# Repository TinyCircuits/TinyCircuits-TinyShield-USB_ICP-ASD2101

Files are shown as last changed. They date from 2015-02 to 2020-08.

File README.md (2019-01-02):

# TinyCircuits TinyShield USB & ICP Board
# ASD2101 Rev6

The design files are located under design-files/ for the TinyCircuits ASD2101 Rev 6 PCB.  This is a TinyShield board (Square Version, 20mm x 20mm) that has a FTDI USB converter.

Format is in Cadsoft Eagle format - Eagle version 6.2 was used for the original design.

For more infomation on this, check out the product page at TinyCircuits.com:  https://tinycircuits.com/collections/communication/products/usb-tinyshield

# License:

Design by TinyCircuits.
All design files are released under the Creative Commons Attribution Share-Alike 3.0 License, see the following link for details: http://creativecommons.org/licenses/by-sa/3.0

All text above must be included in any redistribution or derived design

This project uses designs and concepts developed as part of the Arduino project and the LilyPad project.  The TinyCircuits design files themselves (schematics, PCB and libraries) are not directly derived from these works' design files and have been created new, however the concepts and basic architecture behind the TinyDuino and TinyLily products are derived and we thank the hard work of the organizations below for their contributions to open-source hardware:
  
Original Arduino Uno Design by Team Arduino

LilyPad Arduino Design by Leah Buechley and Sparkfun Electronics

Please support the open-source hardware community

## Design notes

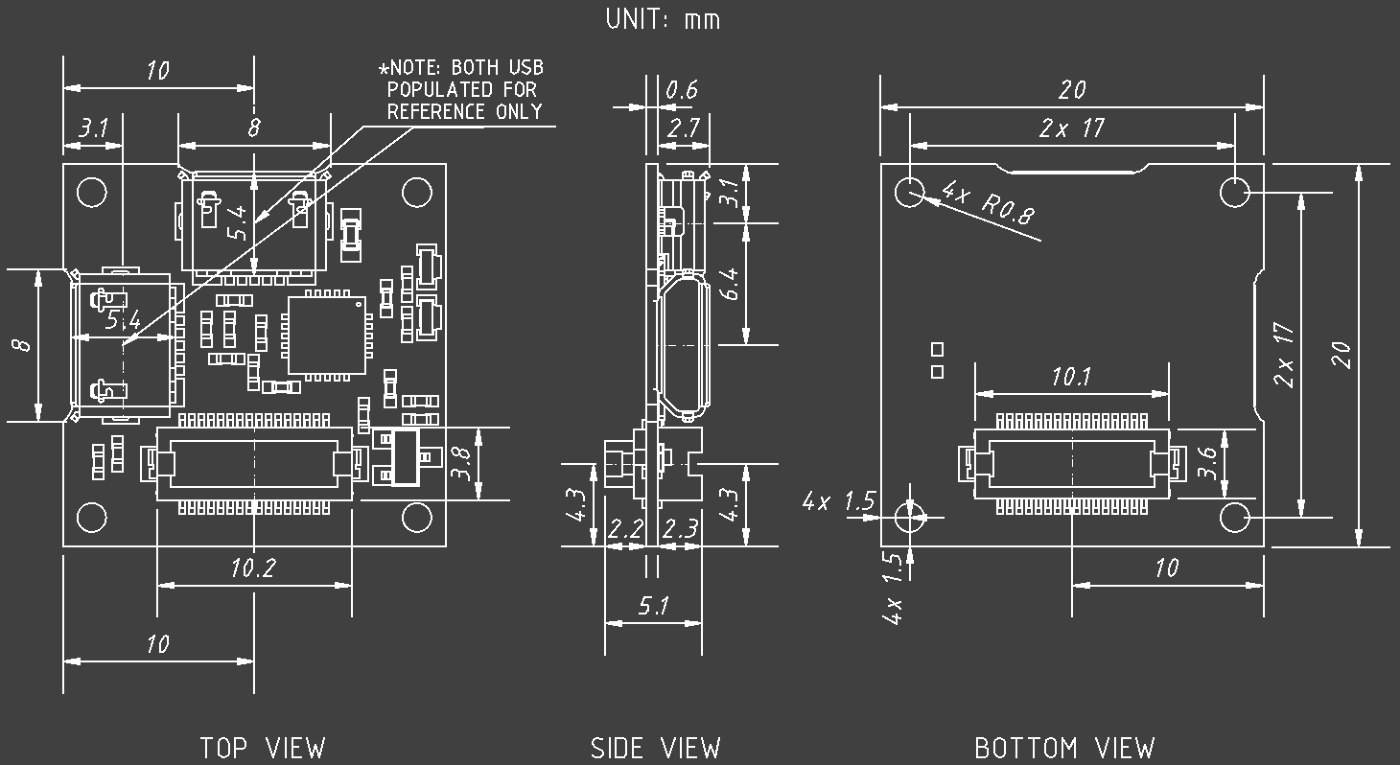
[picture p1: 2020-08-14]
cad/TinyShield_USBICP_ASD2101_REV6-DETAILED_DRAWING_COMPACT-PNG.png

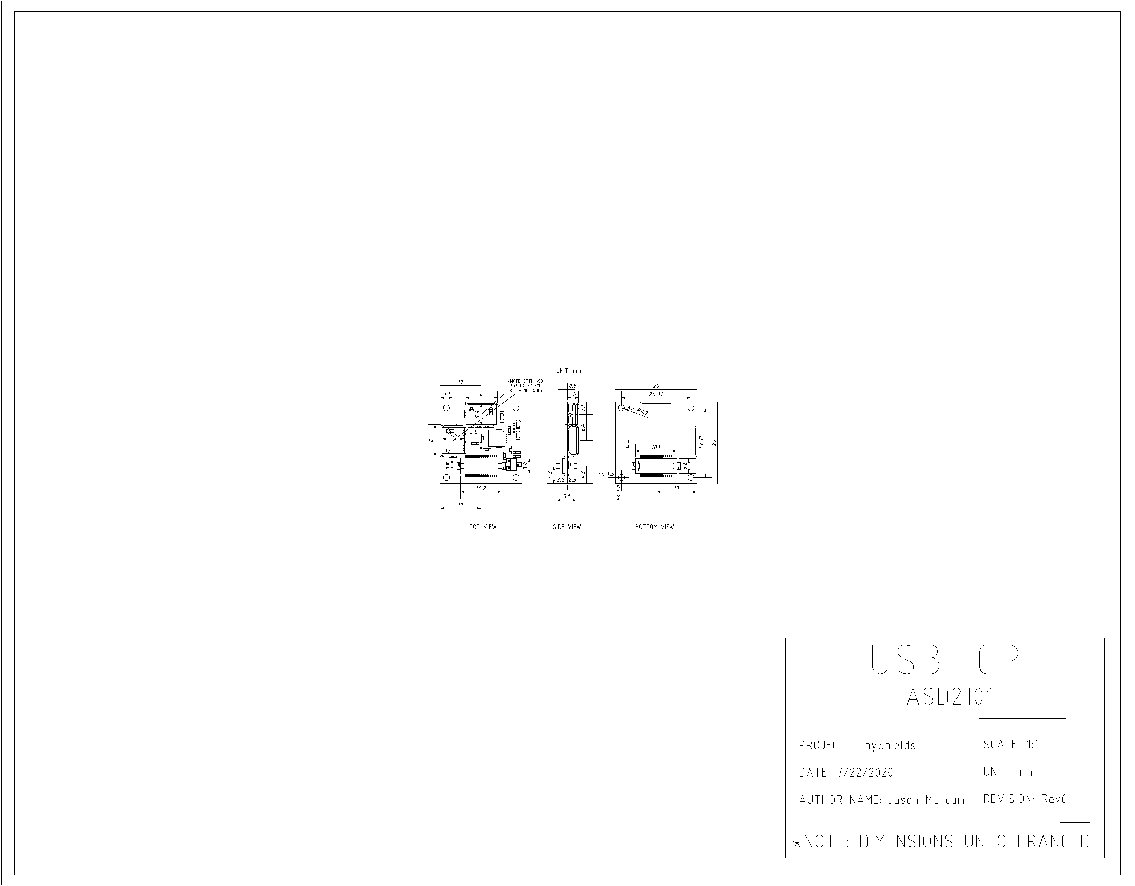
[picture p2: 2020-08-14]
cad/TinyShield_USBICP_ASD2101_REV6-DETAILED_DRAWING-PNG.png

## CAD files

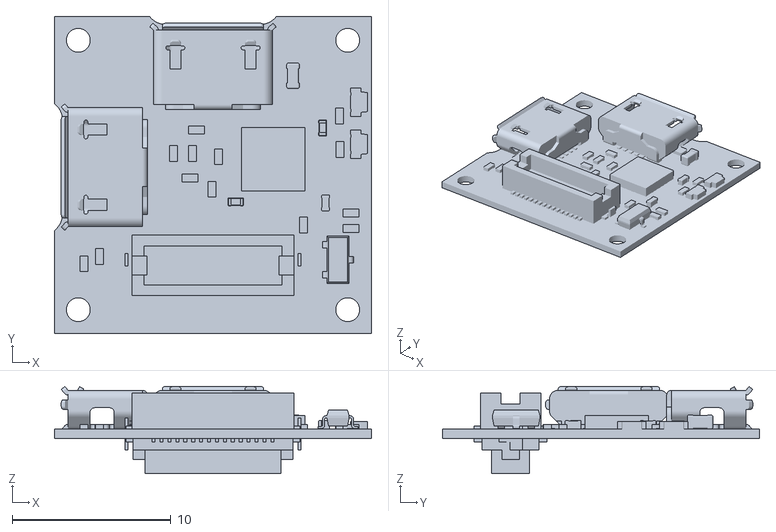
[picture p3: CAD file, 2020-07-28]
cad/TinyShield_USBICP_ASD2101_REV6-STL.stl
20.0 x 20.0 x 5.50

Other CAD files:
cad/TinyShield_USBICP_ASD2101_REV6-DETAILED_DRAWING-DXF.dxf

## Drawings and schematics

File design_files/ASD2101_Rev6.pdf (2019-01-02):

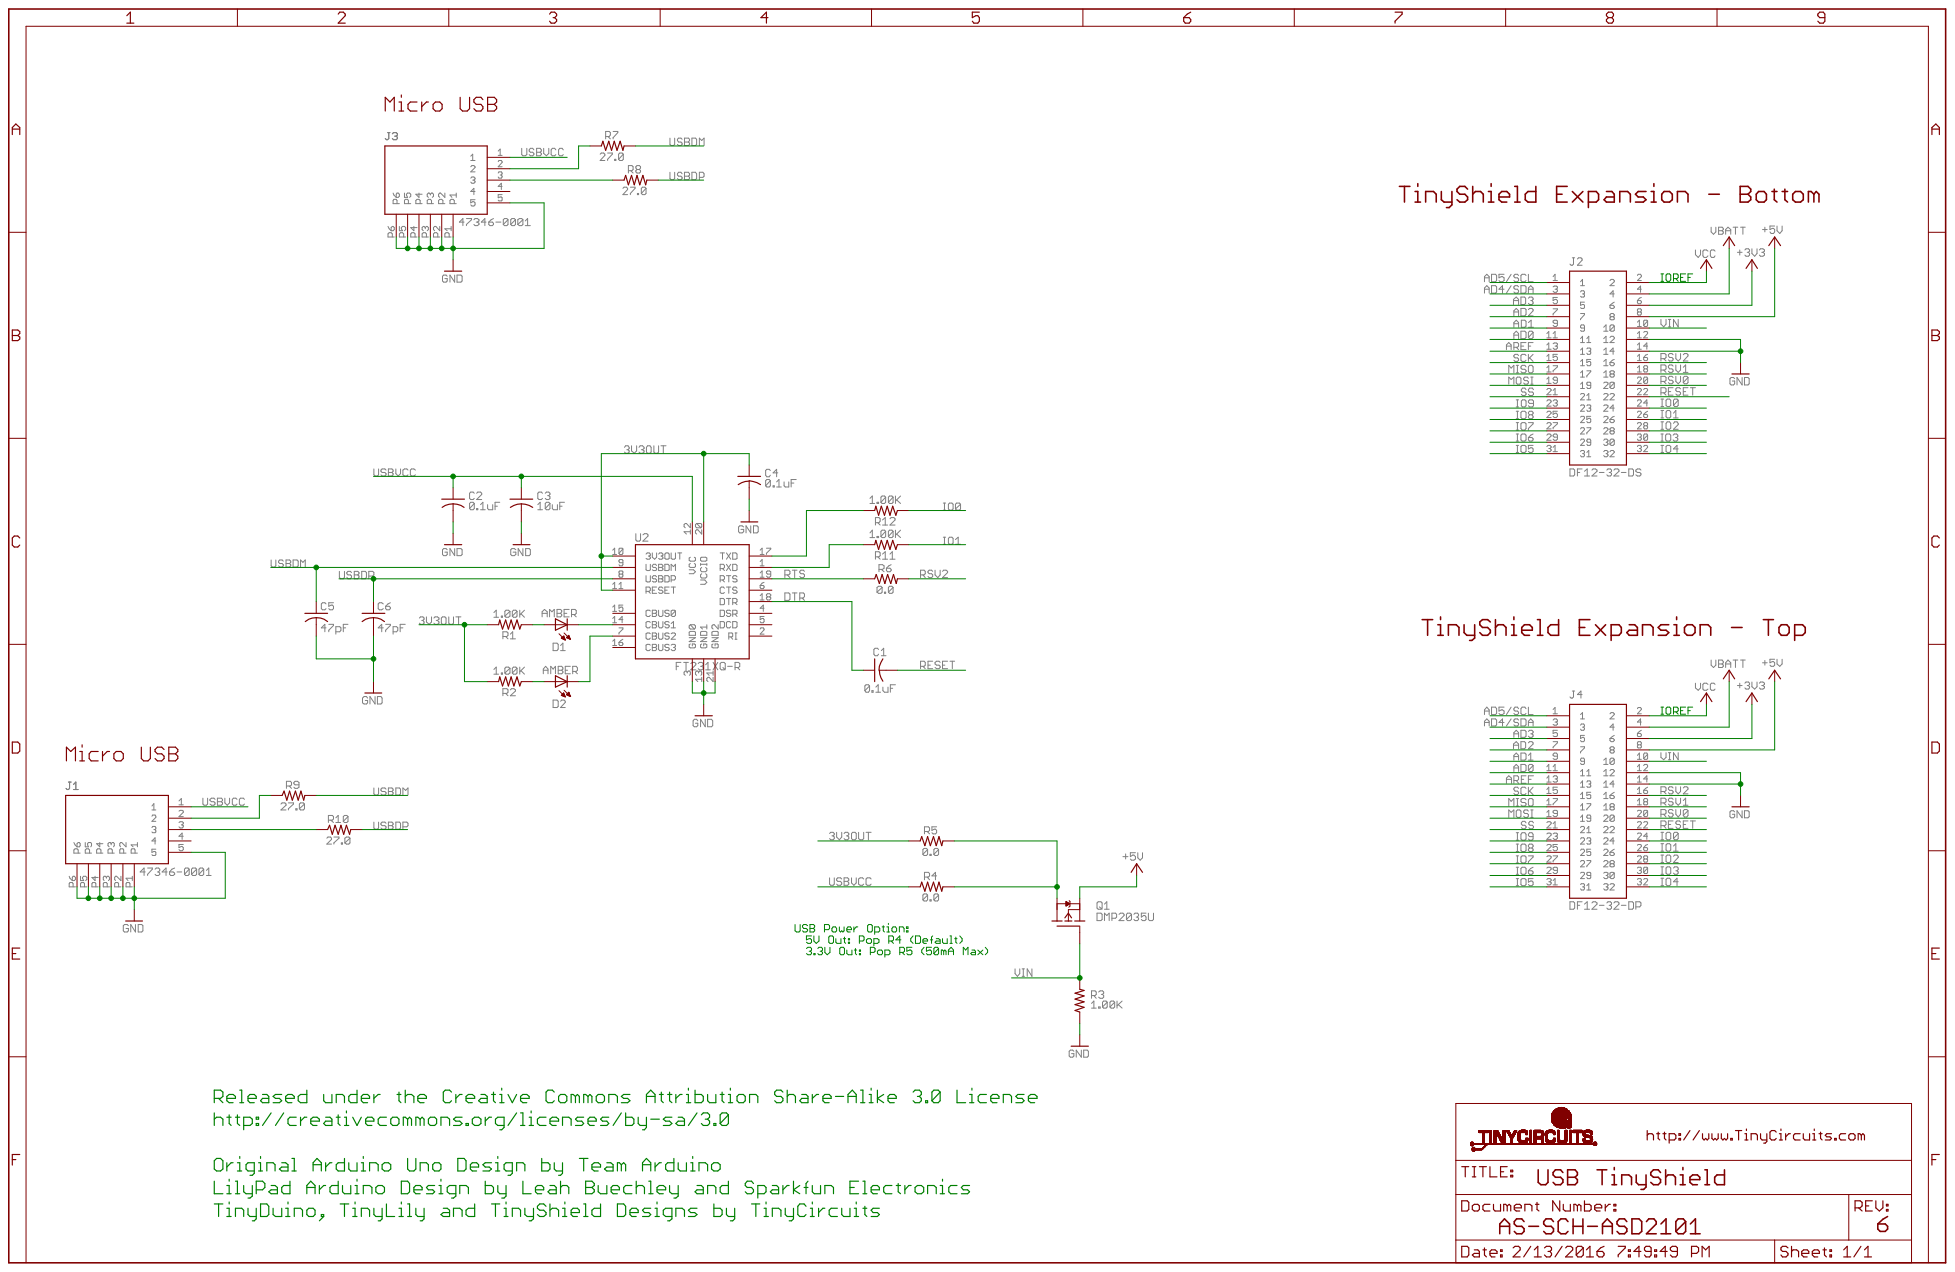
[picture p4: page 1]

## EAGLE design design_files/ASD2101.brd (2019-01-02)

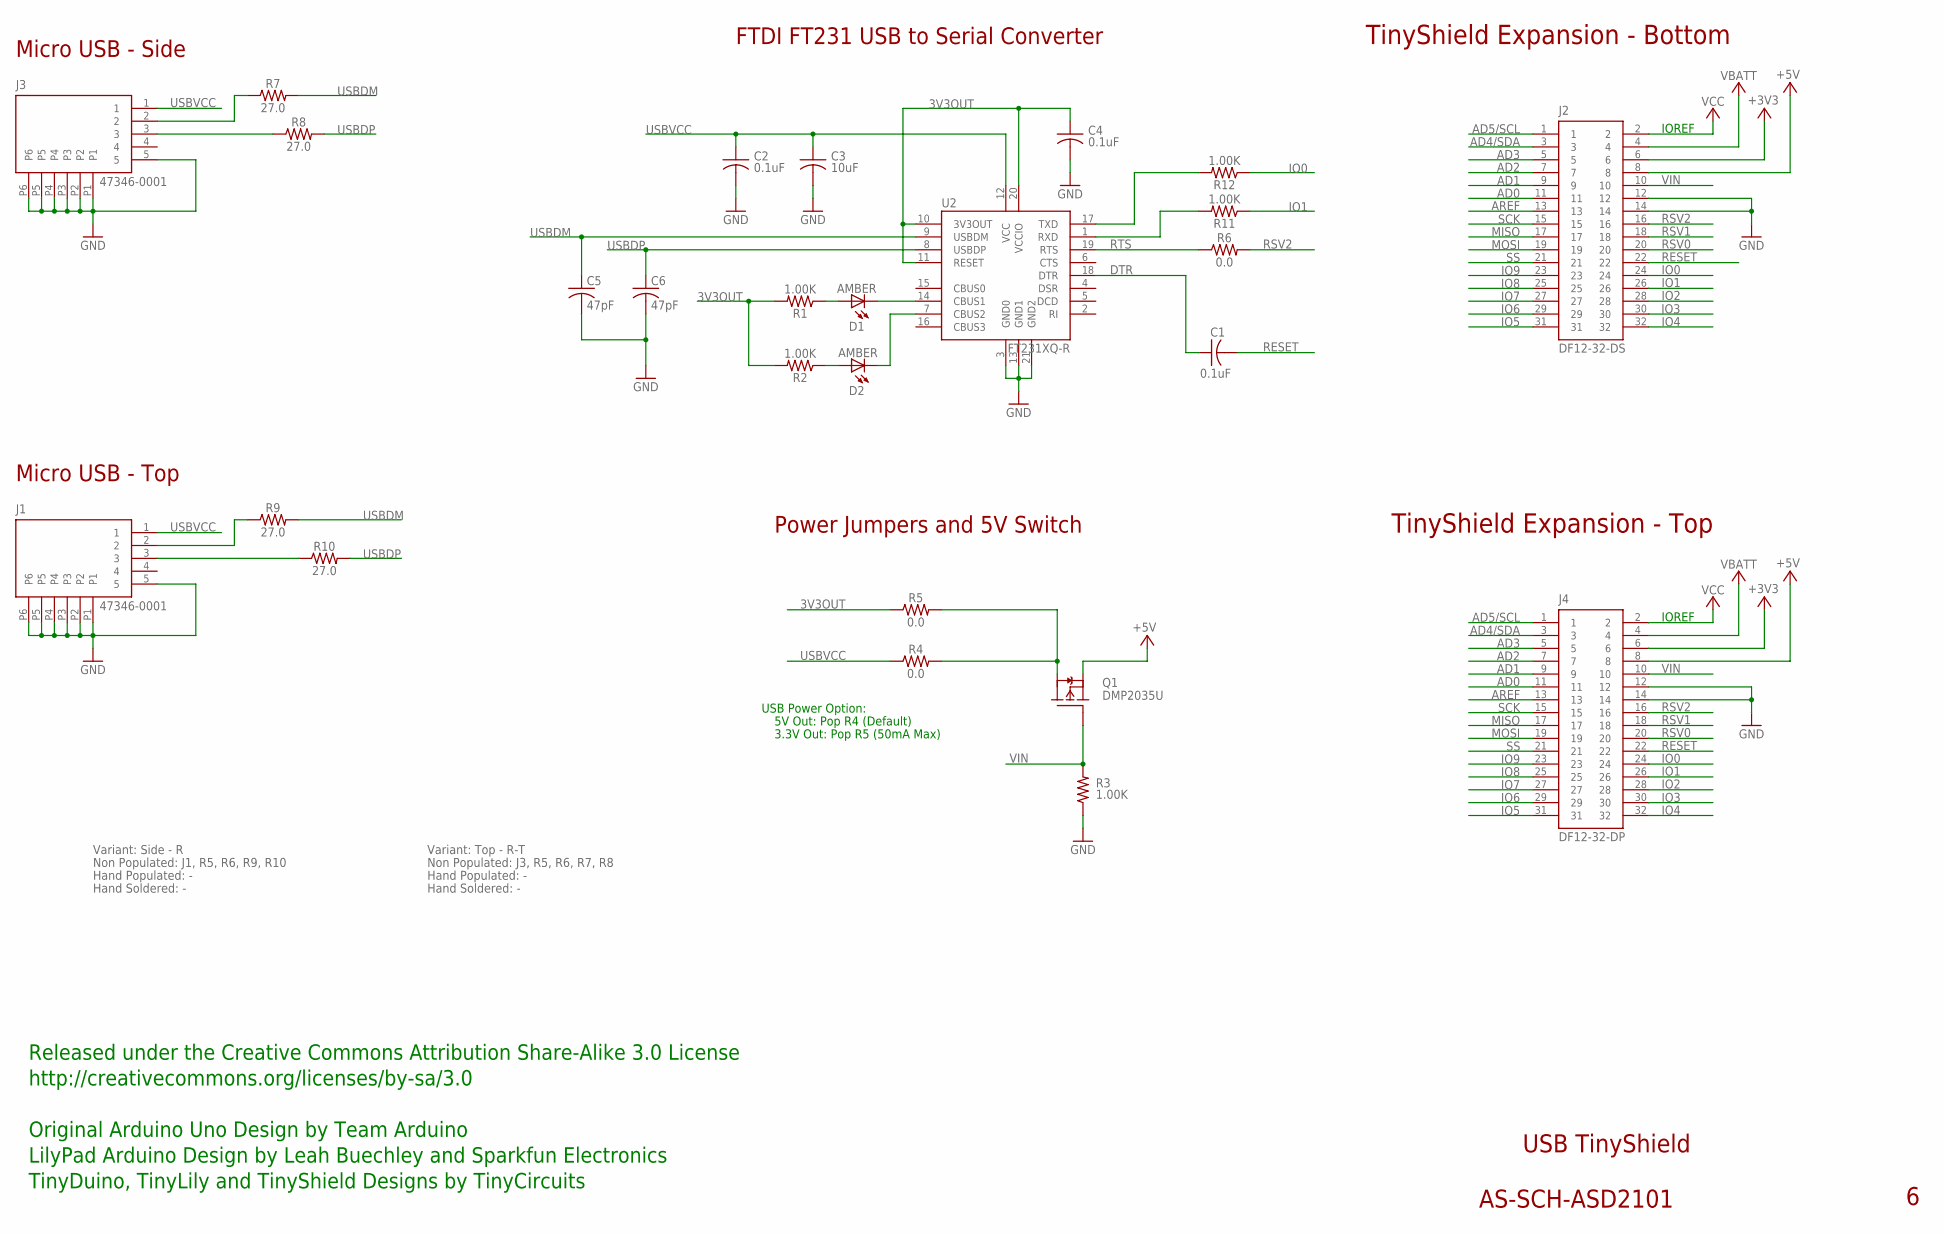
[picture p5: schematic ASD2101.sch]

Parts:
C1, C4: 0.1uF; C0402; PARTNO AS-ITM-00008
C2: 0.1uF; C0402
C3: 10uF; C0603
C5, C6: 47pF; 0402; PARTNO AS-ITM-00241
D1, D2: AMBER; LNJ_LED
J1, J3: 47346-0001; MICRO_USB; PARTNO AS-ITM-00021
J2: DF12-32-DS; PARTNO AS-ITM-00012
J4: DF12-32-DP; PARTNO AS-ITM-00015
Q1: DMP2035U; SOT23
R1, R2, R3: 1.00K; 0402
R4, R5: 0.0; 0402
R6: 0.0; 0402_SHORT
R7, R8, R9, R10: 27.0; 0402
R11, R12: 1.00K; 0402; PARTNO AS-ITM-00003
U2: FT231XQ-R; QFN20

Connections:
3V3OUT: C4.1, R1.2, R2.2, R5.1, U2.10 (3V3OUT), U2.11 (RESET), U2.20 (VCCIO)
+3V3: J2.6, J4.6
+5V: J2.8, J4.8, Q1.E (S)
AD0: J2.11, J4.11
AD1: J2.9, J4.9
AD2: J2.7, J4.7
AD3: J2.5, J4.5
AD4/SDA: J2.3, J4.3
AD5/SCL: J2.1, J4.1
AREF: J2.13, J4.13
DTR: C1.1, U2.18 (DTR)
GND: C2.2, C3.2, C4.2, C5.2, C6.2, J1.5, J1.P1, J1.P2, J1.P3, J1.P4, J1.P5, J1.P6, J2.12, J2.14, J3.5, J3.P1, J3.P2, J3.P3, J3.P4, J3.P5, J3.P6, J4.12, J4.14, R3.1, U2.3 (GND0), U2.13 (GND1), U2.21 (GND2)
IO0: J2.24, J4.24, R12.1
IO1: J2.26, J4.26, R11.1
IO2: J2.28, J4.28
IO3: J2.30, J4.30
IO4: J2.32, J4.32
IO5: J2.31, J4.31
IO6: J2.29, J4.29
IO7: J2.27, J4.27
IO8: J2.25, J4.25
IO9: J2.23, J4.23
MISO: J2.17, J4.17
MOSI: J2.19, J4.19
unnamed: J3.2, R7.1
unnamed: J1.2, R9.1
unnamed: J1.3, R10.1
unnamed: Q1.C (D), R4.2, R5.2
unnamed: D2.C, U2.7 (CBUS2)
unnamed: D1.A, R1.1
unnamed: D2.A, R2.1
unnamed: J3.3, R8.1
unnamed: R11.2, U2.1 (RXD)
unnamed: R12.2, U2.17 (TXD)
unnamed: D1.C, U2.14 (CBUS1)
RESET: C1.2, J2.22, J4.22
RSV0: J2.20, J4.20
RSV1: J2.18, J4.18
RSV2: J2.16, J4.16, R6.2
RTS: R6.1, U2.19 (RTS)
SCK: J2.15, J4.15
SS: J2.21, J4.21
USBDM: C5.1, R7.2, R9.2, U2.9 (USBDM)
USBDP: C6.1, R8.2, R10.2, U2.8 (USBDP)
USBVCC: C2.1, C3.1, J1.1, J3.1, R4.1, U2.12 (VCC)
VBATT: J2.4, J4.4
VCC: J2.2, J4.2
VIN: J2.10, J4.10, Q1.B (G), R3.2

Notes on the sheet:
TinyShield Expansion - Bottom
USB TinyShield
AS-SCH-ASD2101
TinyShield Expansion - Top
IOREF
Micro USB - Side
Released under the Creative Commons Attribution Share-Alike 3.0 License
http://creativecommons.org/licenses/by-sa/3.0
Original Arduino Uno Design by Team Arduino
TinyDuino, TinyLily and TinyShield Designs by TinyCircuits
LilyPad Arduino Design by Leah Buechley and Sparkfun Electronics
USB Power Option:
5V Out: Pop R4 (Default)
3.3V Out: Pop R5 (50mA Max)
Micro USB - Top
FTDI FT231 USB to Serial Converter
Power Jumpers and 5V Switch
Non Populated: J1, R5, R6, R9, R10
Hand Populated: -
Hand Soldered: -
Variant: Side - R
Non Populated: J3, R5, R6, R7, R8
Variant: Top - R-T

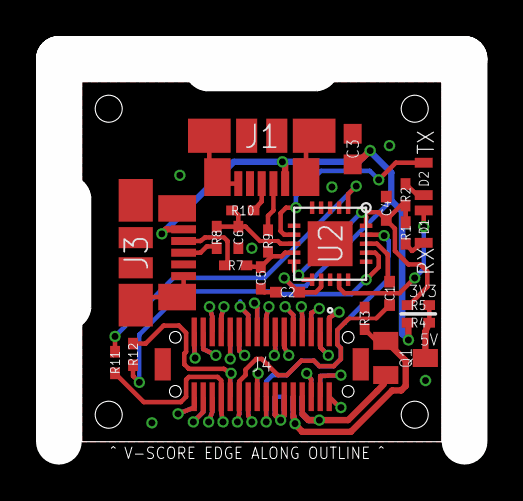
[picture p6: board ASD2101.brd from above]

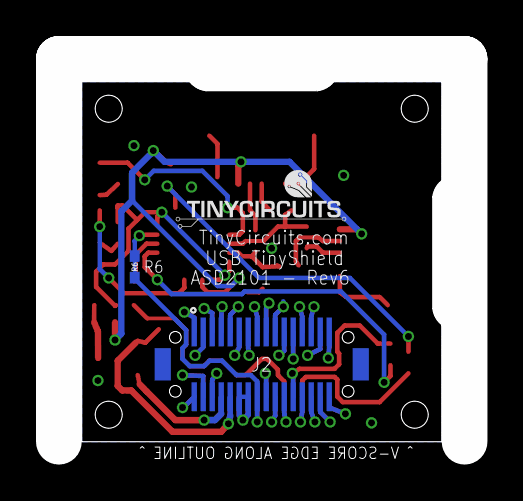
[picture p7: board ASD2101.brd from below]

Board: 2 copper layers, 20.0 x 20.0 mm, 27 parts (2 on the bottom side), 48 nets.

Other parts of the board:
U$1: DOCFIELD-TINYCIRCUITS-PCB

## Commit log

2013-12-22 Updated to Rev4
    [ASD2101.brd, ASD2101.sch]
2015-02-22 Updated to Rev 6
    [ASD2101.brd, ASD2101.sch]
2019-01-02 update format
    [ASD2101.brd, ASD2101.sch]
2020-07-28 Add CAD data
    [TinyShield_USBICP_ASD2101_REV6-DETAILED_DRAWING-DXF.dxf, TinyShield_USBICP_ASD2101_REV6-STL.stl]
2020-08-14 Update CAD drawing
    [TinyShield_USBICP_ASD2101_REV6-DETAILED_DRAWING-DXF.dxf]
